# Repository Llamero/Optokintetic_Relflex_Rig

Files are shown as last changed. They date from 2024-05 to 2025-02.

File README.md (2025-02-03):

# Optokinetic Reflex Behavior Rig
 This is an open-source behavior rig designed to accurately the optokinetic reflex in mice.  This design is a derivative of the following designs:
 * https://pmc.ncbi.nlm.nih.gov/articles/PMC10023158/
 * https://www.jneurosci.org/content/37/5/1102
 
 The development of this scope and illuminator was funded by the following grant: NIH P30EY003176
 
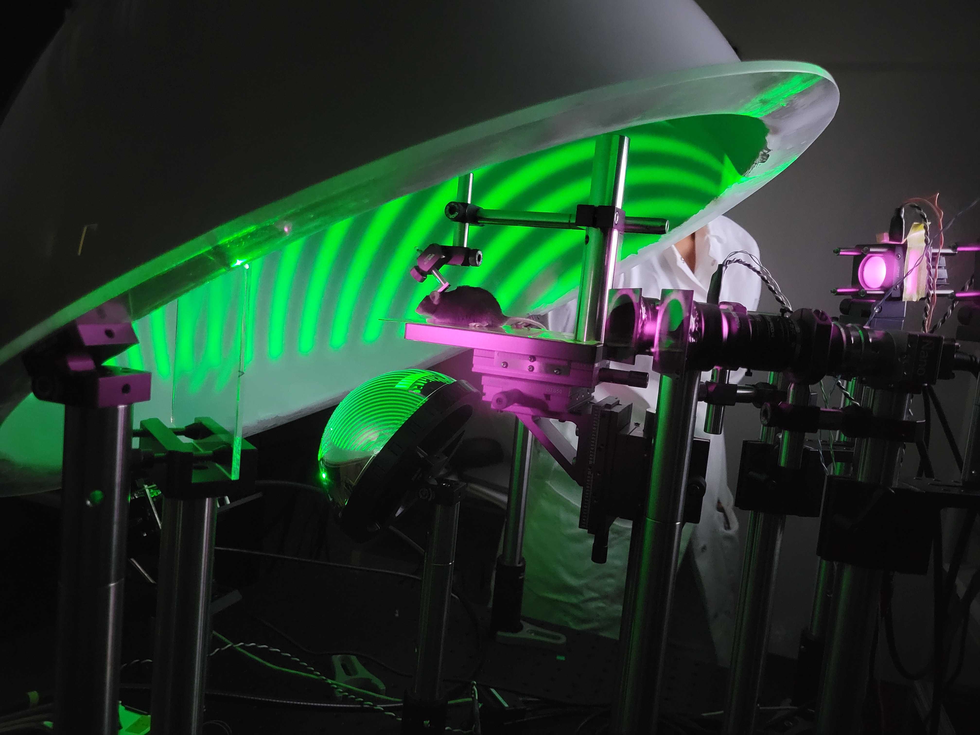
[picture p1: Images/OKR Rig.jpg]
 
 
## How to use the CAD files
The CAD files can be opened using FreeCAD: https://www.freecadweb.org/downloads.php  Unless otherwise specified, all the part numbers listed in the CAD file are Thorlabs part numbers.
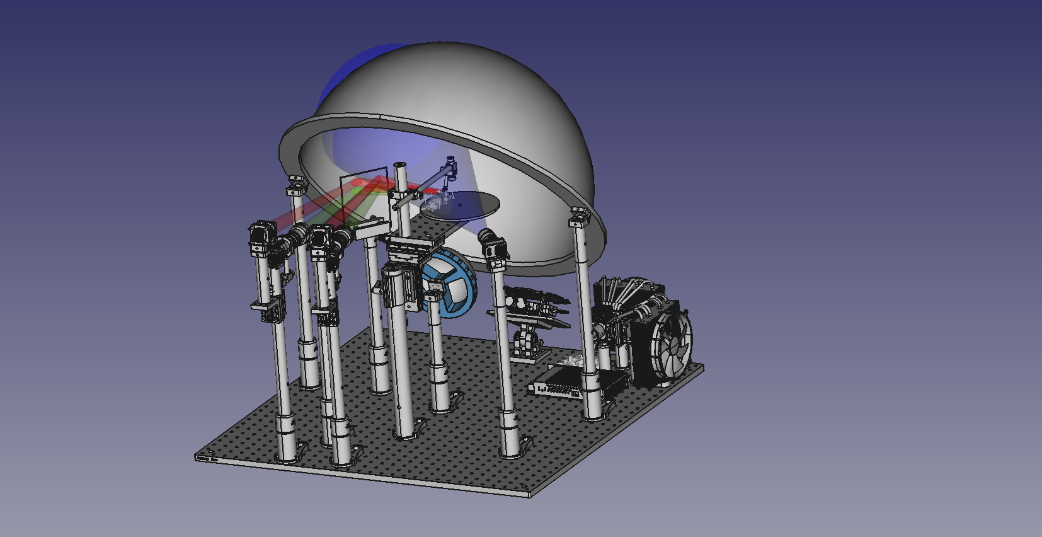
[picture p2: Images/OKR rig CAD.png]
 
 
## Controlling the LEDs
The green (l-cone) and UV (s-cone) 27 amp LEDs are directly controlled via the RGB LED control channels on the EKB DLP.  These 3v3 outputs are shifted to 12V with a gate driver, which is then used to switch mosfets in series with the LEDs.  Ballast resistors control the current.

All circuit design files can be found in the KiCAD filder, and opened using KiCAD: https://www.kicad.org/download/

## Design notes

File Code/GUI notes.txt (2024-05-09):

Change color of Frame Buffer spinbox depending on the level of binning required

Auto save data on save click

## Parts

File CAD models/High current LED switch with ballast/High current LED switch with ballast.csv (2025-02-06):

Item | Qty | Reference(s) | Value | LibPart | Footprint | Datasheet | DNP | Manufacturer | Part
1 | 4 | C1, C2, C3, C4 | 9.1mF | Device:C_Polarized_Small_US | Custom footprints:CAP_FKS_K21_PAN | https://industrial.panasonic.com/cdbs/www-data/pdf/RDE0000/ABA0000C1247.pdf |  | Panasonic Electronic Components | EEE-FK1A912SM
2 | 3 | D1, D2, D3 | D_TVS | Device:D_TVS | Custom footprints:DO-214AB | https://www.yageo.com/upload/media/product/products/datasheet/cpc/tvs/SMDJ_1.pdf |  | YAGEO | SMDJ60A/TR13
3 | 4 | HS1, HS2, HS3, HS4 | Heatsink | Mechanical:Heatsink | Custom footprints:31mm heatsink | https://wakefieldthermal.com/content/data_sheets/PIN%20FIN%20HEAT%20SINK.pdf |  | Wakefield-Vette | 906-31-2-23-2-B-0
4 | 10 | J1, J2, J3, J4, J6, J7, J8, J9, J10, J11 | Conn_01x01_Pin | Connector:Conn_01x01_Pin | Custom footprints:KEYSTONE_4928 | https://www.keyelco.com/product-pdf.cfm?p=14309 |  | Keystone Electronics | 4928
5 | 1 | J5 | Conn_01x04_Pin | Connector:Conn_01x04_Pin | Connector_PinHeader_2.54mm:PinHeader_1x04_P2.54mm_Vertical_SMD_Pin1Right | https://cdn.harwin.com/pdfs/M20-877.pdf |  | Harwin Inc. | M20-8770442
6 | 3 | Q1, Q2, Q3 | Q_NMOS_GDS | Device:Q_NMOS_GDS | Package_TO_SOT_SMD:TO-263-2 | http://www.gofordsemi.com/u_file/product/709/GOFORD-GT035N10M.pdf |  | Goford Semiconductor | GT035N10M
7 | 1 | R1 | 1000 | Device:R | Resistor_SMD:R_1206_3216Metric | https://www.seielect.com/catalog/sei-rmcf_rmcp.pdf |  | Stackpole Electronics Inc | RMCF1206FT1K00
8 | 2 | R2, R5 | 0 | Device:R | Custom footprints:R_2818 | https://www.koaspeer.com/pdfs/TLRZ.pdf |  | KOA Speer Electronics, Inc. | TLRZ2BTTD
9 | 3 | R3, R7, R9 | 25m | Device:R | Custom footprints:R_2818 | https://www.vishay.com/docs/30347/wshp2818.pdf |  | Vishay Dale | WSHP2818R0250FEA
10 | 7 | R4, R6, R8, R10, R11, R12, R13 | R | Device:R | Custom footprints:R_2818 | ~

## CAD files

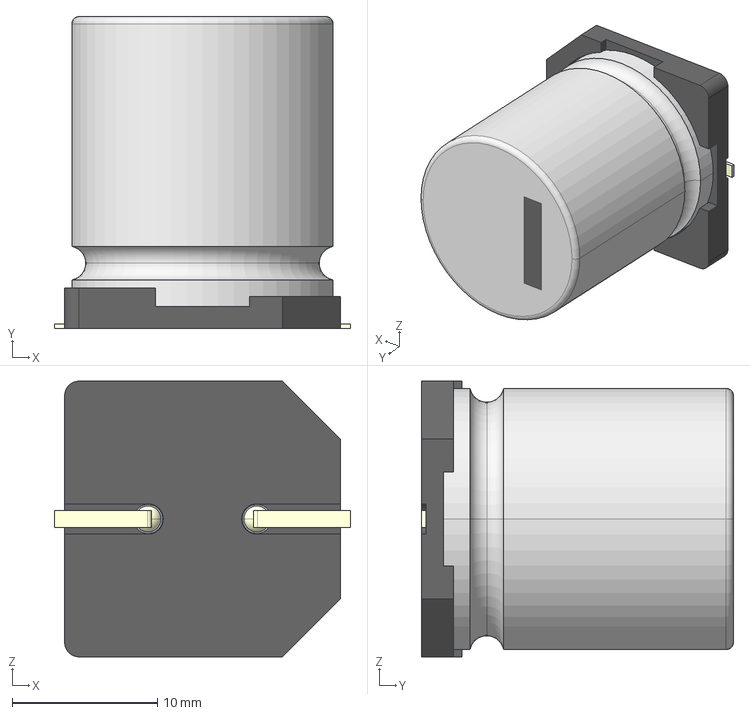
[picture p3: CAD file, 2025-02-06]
CAD models/High current LED switch with ballast/STEP/18 SIZE CODE K21.stp
20.4 x 21.5 x 19.0 mm

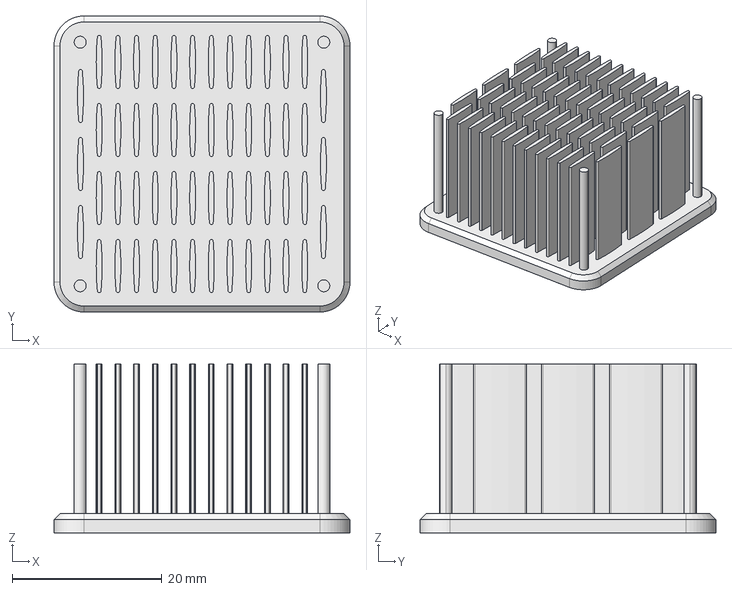
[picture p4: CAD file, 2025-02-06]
CAD models/High current LED switch with ballast/STEP/910-40-1-23-X-B-0.STEP
39.6 x 39.6 x 22.6 mm

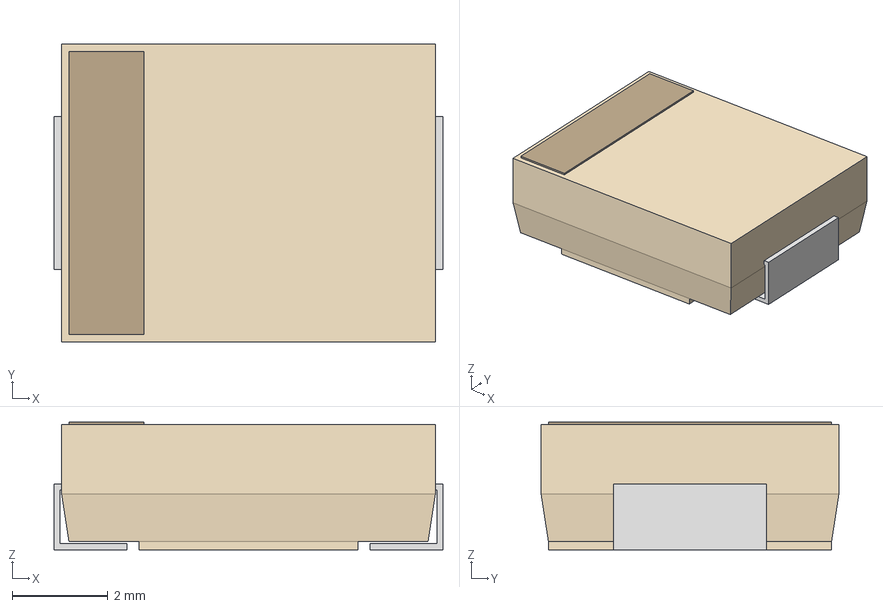
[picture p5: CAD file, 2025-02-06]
CAD models/High current LED switch with ballast/STEP/5_0SMDJSeries_LTF.step
8.13 x 6.22 x 2.67 mm

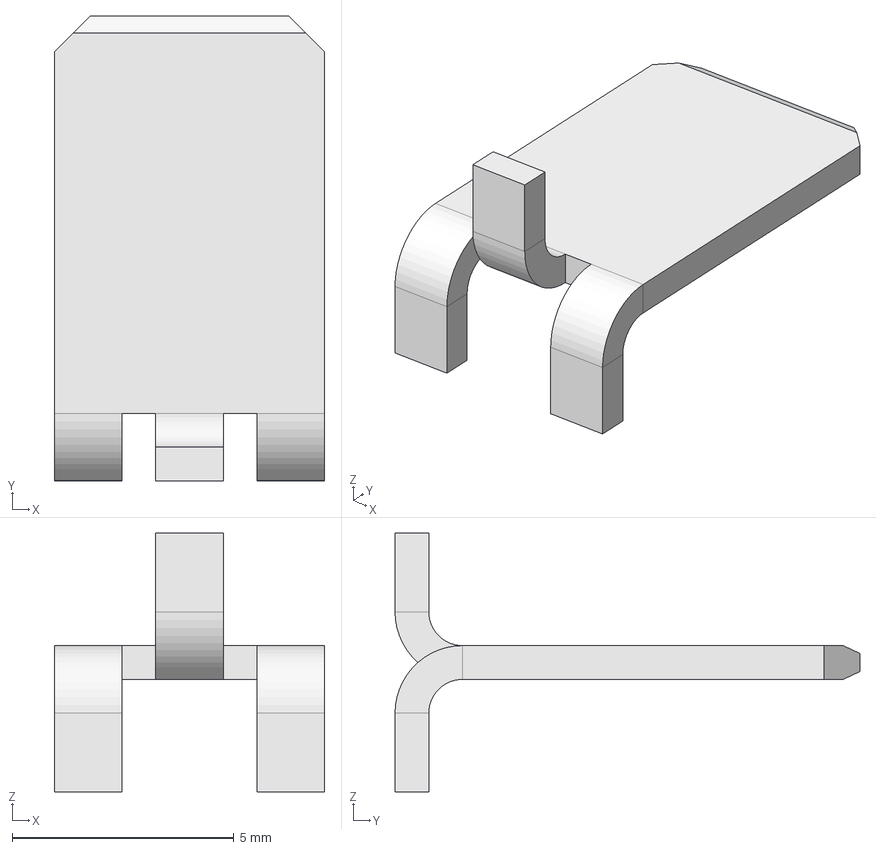
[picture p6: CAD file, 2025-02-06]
CAD models/High current LED switch with ballast/STEP/4928.step
6.10 x 10.5 x 5.84 mm

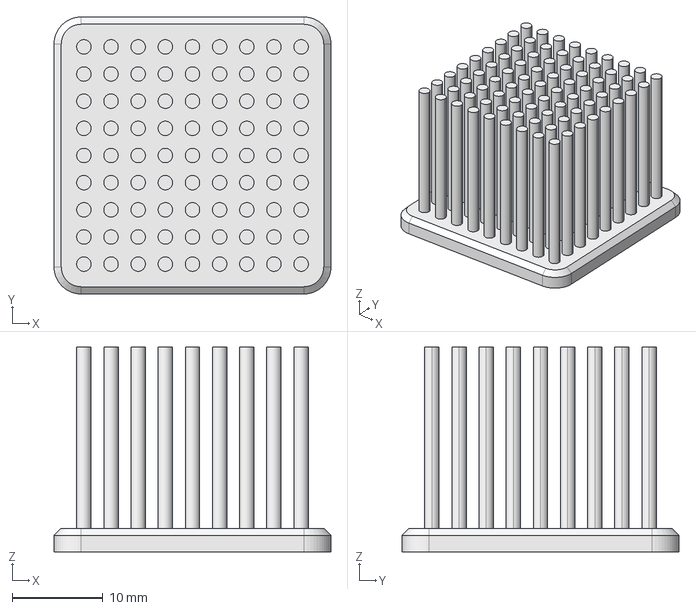
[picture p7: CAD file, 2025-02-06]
CAD models/High current LED switch with ballast/STEP/906-31-2-23-2-B-0.STEP
30.6 x 30.6 x 22.6 mm

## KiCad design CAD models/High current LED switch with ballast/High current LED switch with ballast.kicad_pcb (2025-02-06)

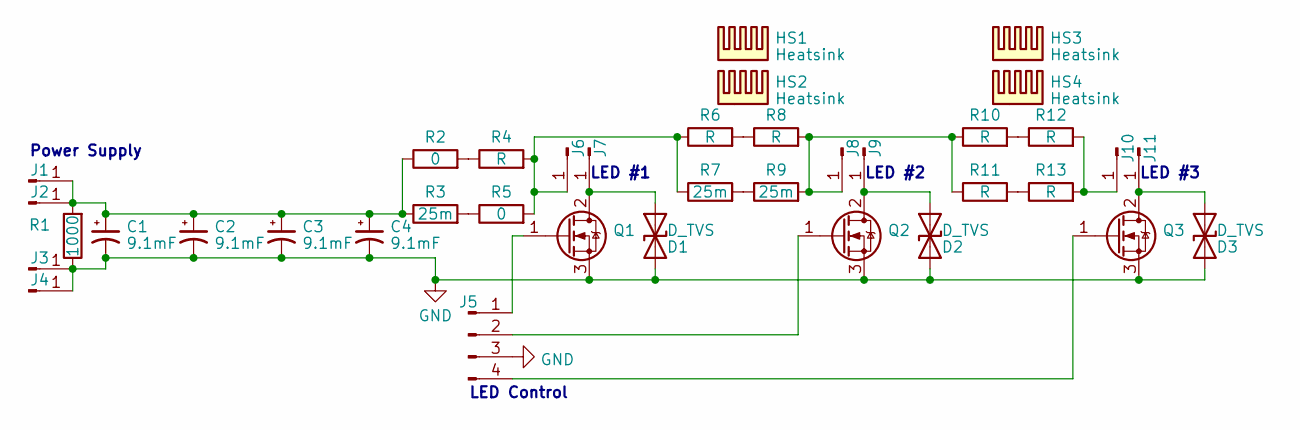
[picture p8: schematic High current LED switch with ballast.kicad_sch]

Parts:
C1, C2, C3, C4: 9.1mF; CAP_FKS_K21_PAN; Part EEE-FK1A912SM
D1, D2, D3: D_TVS; DO-214AB; Part SMDJ60A/TR13
HS1, HS2, HS3, HS4: Heatsink; 31mm heatsink; Part 906-31-2-23-2-B-0
J1, J2, J3, J4, J6, J7, J8, J9, J10, J11: Conn_01x01_Pin; KEYSTONE_4928; Part 4928
J5: Conn_01x04_Pin; PinHeader_1x04_P2.54mm_Vertical_SMD_Pin1Right; Part M20-8770442
Q1, Q2, Q3: Q_NMOS_GDS; TO-263-2; Part GT035N10M
R1: 1000; R_1206_3216Metric; Part RMCF1206FT1K00
R2, R5: 0; R_2818; Part TLRZ2BTTD
R3, R7, R9: 25m; R_2818; Part WSHP2818R0250FEA
R4, R6, R8, R10, R11, R12, R13: R; R_2818

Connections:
GND: C1.2, C2.2, C3.2, C4.2, D1.2 (A2), D2.2 (A2), D3.2 (A2), J3.1, J4.1, J5.3, Q1.3 (S), Q2.3 (S), Q3.3 (S), R1.1
unnamed: D1.1 (A1), J7.1, Q1.2 (D)
unnamed: D2.1 (A1), J9.1, Q2.2 (D)
unnamed: D3.1 (A1), J11.1, Q3.2 (D)
unnamed: C1.1, C2.1, C3.1, C4.1, J1.1, J2.1, R1.2, R2.1, R3.1
unnamed: J5.1, Q1.1 (G)
unnamed: J5.2, Q2.1 (G)
unnamed: J5.4, Q3.1 (G)
unnamed: J6.1, R4.2, R5.2, R6.1, R7.1
unnamed: J8.1, R8.2, R9.2, R10.1, R11.1
unnamed: J10.1, R12.2, R13.2
unnamed: R2.2, R4.1
unnamed: R3.2, R5.1
unnamed: R6.2, R8.1
unnamed: R7.2, R9.1
unnamed: R10.2, R12.1
unnamed: R11.2, R13.1

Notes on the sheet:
LED #1
Power Supply
LED #3
LED Control
LED #2

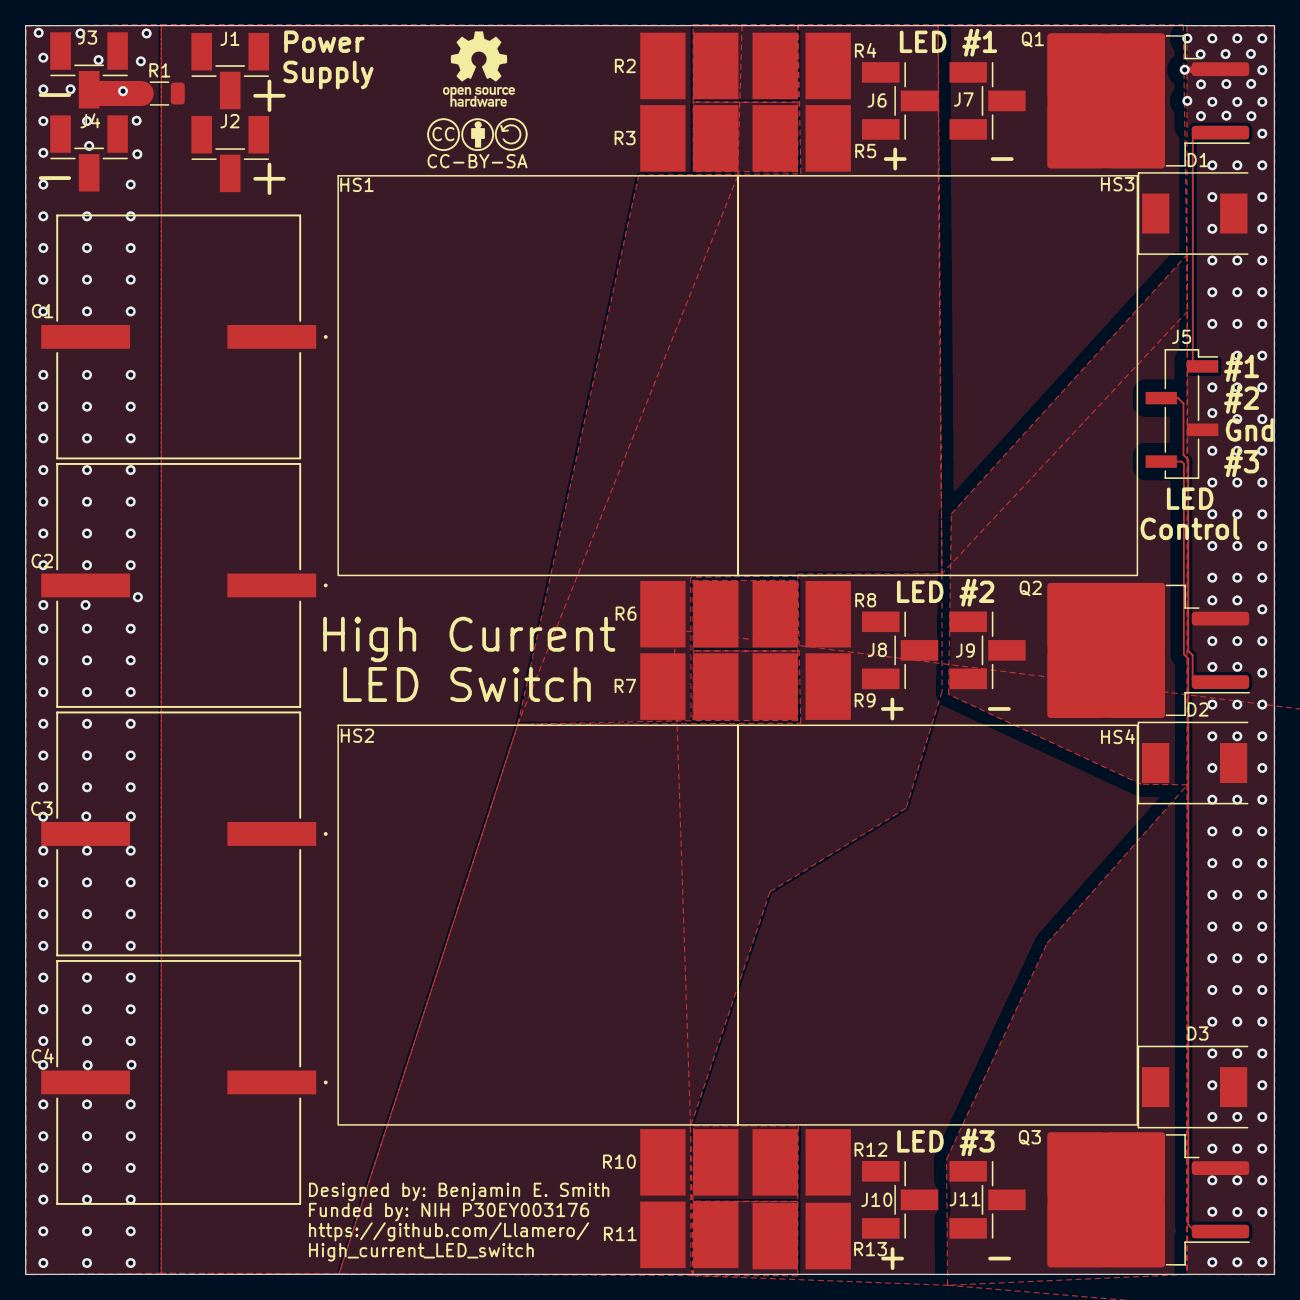
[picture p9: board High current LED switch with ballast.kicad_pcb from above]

Board: 2 copper layers, 100.0 x 100.0 mm, 38 parts (0 on the bottom side), 17 nets.

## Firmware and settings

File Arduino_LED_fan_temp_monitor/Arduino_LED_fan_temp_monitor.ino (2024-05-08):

// SPDX-FileCopyrightText: 2011 Limor Fried/ladyada for Adafruit Industries
//
// SPDX-License-Identifier: MIT

// Thermistor Example #3 from the Adafruit Learning System guide on Thermistors 
// https://learn.adafruit.com/thermistor/overview by Limor Fried, Adafruit Industries
// MIT License - please keep attribution and consider buying parts from Adafruit
       
// resistance at 25 degrees C
#define THERMISTORNOMINAL 10000      
// temp. for nominal resistance (almost always 25 C)
#define TEMPERATURENOMINAL 25   
// how many samples to take and average, more takes longer
// but is more 'smooth'
#define NUMSAMPLES 64
// The beta coefficient of the thermistor (usually 3000-4000)
#define BCOEFFICIENT 3428
// the value of the 'other' resistor
#define SERIESRESISTOR 4700
// Temp (°C) for min fan speed
#define FANMINTEMP 25
// Temp (°C) for max fan speed
#define FANMAXTEMP 27
//Maximum allowed fanspeed (0-255).  Low = quieter + hotter.
#define MAXFANSPEED 200
//Temperature threshold for audible alarm
#define ALARMTEMP 50

#include <elapsedMillis.h>
float thermistor_temp[2];
const uint8_t FAN_PIN[3] = {10, 9, 11};
elapsedMillis serial_timer;
elapsedMicros alarm_timer;

void setup(void) {
  Serial.begin(9600);
  DDRD = B11111100;
  PORTD = B01100000;
  pinMode(12, OUTPUT);
}

void loop(void) {
  uint8_t i;
  float ADC_temp[2];
  float fan_speed[2];
  uint8_t fan_pwm;
  bool alarm = false;

  // take N samples in a row, with a slight delay
  i = NUMSAMPLES;
  analogRead(A0); //Clear ADC
  ADC_temp[0] = 0;
  while(i--) ADC_temp[0] += analogRead(A0);
  i = NUMSAMPLES;
  analogRead(A1); //Clear ADC
  ADC_temp[1] = 0;
  while(i--) ADC_temp[1] += analogRead(A1);
  
  // convert the value to resistance
  i=2;
  while(i--){
    ADC_temp[i] = 65535 / ADC_temp[i] - 1;
    ADC_temp[i] = SERIESRESISTOR / ADC_temp[i];   
    ADC_temp[i] = ADC_temp[i] / THERMISTORNOMINAL;     // (R/Ro)
    ADC_temp[i] = log(ADC_temp[i]);                  // ln(R/Ro)
    ADC_temp[i] /= BCOEFFICIENT;                   // 1/B * ln(R/Ro)
    ADC_temp[i] += 1.0 / (TEMPERATURENOMINAL + 273.15); // + (1/To)
    ADC_temp[i] = 1.0 / ADC_temp[i];                 // Invert
    ADC_temp[i] -= 273.15;                         // convert absolute temp to C
    
    fan_speed[i] = 255*((ADC_temp[i]-FANMINTEMP)/(FANMAXTEMP-FANMINTEMP));
    if(fan_speed[i] <= 0) fan_speed[i] = 0;
    else if(fan_speed[i] >= MAXFANSPEED) fan_speed[i] = MAXFANSPEED;
    fan_pwm = round(fan_speed[i]);
    if(serial_timer > 1000){
      Serial.print("LED#");
      Serial.print(i);
      Serial.print(": "); 
      Serial.print(ADC_temp[i]);
      Serial.print(" °C, ");
      Serial.print("Fan: "); 
      Serial.print(fan_pwm);
      Serial.print(". ");
      analogWrite(FAN_PIN[i], fan_pwm);
    }
  }
  //Set driver fan speed to match fastest LED fan speed
  if(serial_timer > 1000){
    if (fan_speed[0] > fan_speed[1]) fan_pwm = round(fan_speed[0]);
    else fan_pwm = round(fan_speed[1]);
    Serial.print("Driver fan: ");
    Serial.print(fan_pwm);
    Serial.print(". ");
    analogWrite(FAN_PIN[2], fan_pwm);
    Serial.println();
    serial_timer = 0;
    if (fan_pwm > 0) digitalWrite(12, HIGH); 
    else digitalWrite(12, LOW); 
  }
  if(ADC_temp[0] >= ALARMTEMP || ADC_temp[1] >= ALARMTEMP){
    uint32_t start = serial_timer;
    while(serial_timer - start < 500){
      if(alarm_timer < 166) PORTD = B01101000; 
      else if(alarm_timer < 333) PORTD = B01100100; 
      else alarm_timer = 0;
    }
  }
  else{
    PORTD = B01100000; 
  }
}

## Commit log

2024-03-03 First 3 camera test
2024-03-04 Class vectors!
    Using class pointer vectors to list devices
2024-03-05 Three initialize - boot only camera 1
2024-03-05 Add Class wide selection index variable to track camera selected
2024-03-07 All cameras record, playback doesn't update view.
2024-03-09 Change buffer size for all 3 cameras
2024-03-26 Add arduino code for controlling LEDs
2024-03-26 Fix pins - add 3rd fan
    [Arduino_LED_fan_temp_monitor.ino]
2024-05-08 Fix CM1-DCH fan add Python code to repository
    [Arduino_LED_fan_temp_monitor.ino]
2024-05-08 GUI draft - distinguish nIR cameras from vis camera by text
2025-02-06 Add KiCAD files
    [18 SIZE CODE K21.stp, 4928.step, 5_0SMDJSeries_LTF.step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]

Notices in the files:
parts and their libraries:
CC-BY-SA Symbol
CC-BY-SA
